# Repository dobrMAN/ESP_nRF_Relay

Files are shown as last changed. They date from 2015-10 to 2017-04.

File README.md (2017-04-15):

# ESP_nRF_Relay



Реле для управления освещением на базе ESP8266 и nRF24L01+

Релейная часть программно аппартного комплекса для управления освещением или другими нагрузками.

Реле реализовано на базе симистора BTA16-600 и управляется WiFi модулем ESP8266 (ESP-03) и подключенным к нему радио модулем nRF24L01+ mini.

**Программная часть:**

Будет дорабатываться в плане настройки готового модуля.

На данный момент программная часть вполне работоспособна и тестируется на макетной плате.

**Аппаратная часть:**

Плата и схема в разработке. Плата не готова к производству, это лишь наброски, который требуется доработать и перепроверить.

**Ссылки на компоненты:**

+ BTA16-600 - http://www.ebay.com/sch/i.html?_from=R40&_trksid=p2050601.m570.l1313.TR0.TRC0.H0.TRS0&_nkw=bta16-600b&_sacat=0

+ MOC3061 - http://www.ebay.com/sch/i.html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

+ ESP-03 - http://www.ebay.com/sch/i.html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

+ nRF24 - http://www.ebay.com/sch/i.html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

+ AC/DC - http://www.ebay.com/sch/i.html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

+ И разная мелочевка.

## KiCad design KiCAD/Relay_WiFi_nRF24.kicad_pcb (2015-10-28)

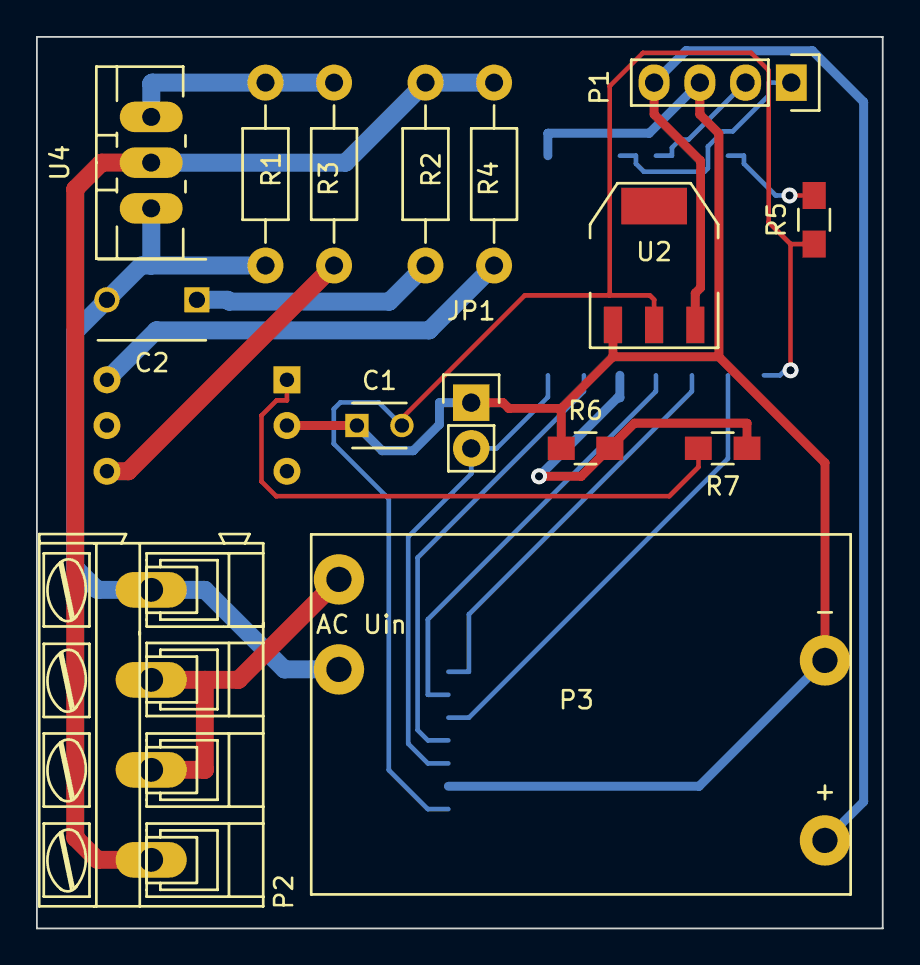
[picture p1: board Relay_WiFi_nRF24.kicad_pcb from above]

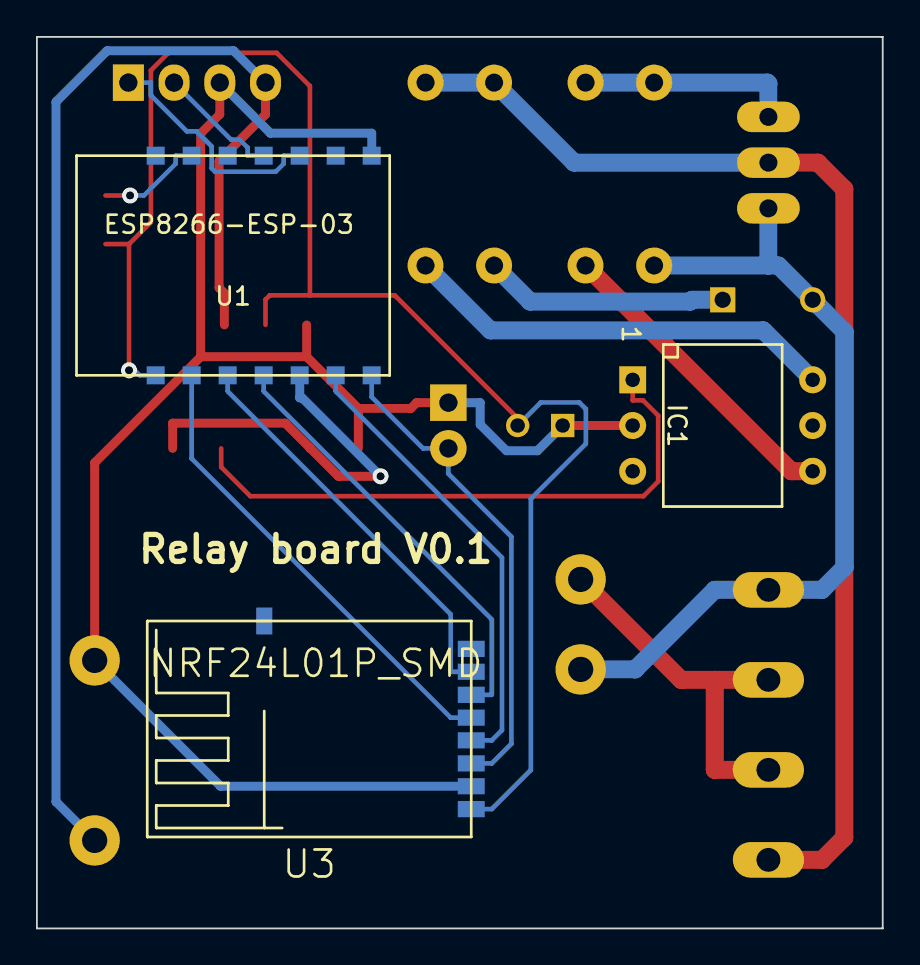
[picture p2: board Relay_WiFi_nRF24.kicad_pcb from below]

Board: 2 copper layers, 47.0 x 49.5 mm, 18 parts (3 on the bottom side), 20 nets.

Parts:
C1: 0.01; C_Disc_D3_P2.5
C2: 10n; C_Disc_D6_P5
IC1: MOC3061M; Optocoupler_6pin_wide_Stile-II
JP1: JUMPER; Pin_Header_Straight_1x02
P1: CONN_4; Pin_Header_Straight_1x04
P2: CONN_4; AK300-4
P3: CONN_01X04; ACDC-FromEbay-5V-700A
R1: 10k; Resistor_Horizontal_RM10mm
R2, R3: 360; Resistor_Horizontal_RM10mm
R4: 39; Resistor_Horizontal_RM10mm
R5, R6: 10k; R_0805_HandSoldering
R7: 220; R_0805_HandSoldering
U1: ESP8266-ESP-03
U2: NCP1117ST33T3G; SOT-223
U3: NRF24L01P_SMD
U4: BTA16; TO-220_Neutral123_Vertical_LargePads

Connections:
GND: C1.1, IC1.2, JP1.1, P1.3, P3.4, R6.1, U1.1, U2.1, U3.2
unnamed: C1.2, R5.1, U1.8, U2.2, U3.1
unnamed: C2.1, R4.2
unnamed: C2.2, P2.4, P3.2, R3.2, U4.1
unnamed: IC1.1, R7.2
unnamed: IC1.4, R1.1
unnamed: IC1.6, R2.1
unnamed: JP1.2, U1.14, U3.3
unnamed: P1.1, U1.3
unnamed: P1.2, U1.4
unnamed: P2.1, R2.2, R4.1, U4.2
unnamed: P2.2, P2.3, P3.1
unnamed: R1.2, R3.1, U4.3
unnamed: R5.2, U1.6
unnamed: R6.2, R7.1, U1.12
unnamed: U1.9, U3.5
unnamed: U1.10, U3.7
unnamed: U1.11, U3.6
unnamed: U1.13, U3.4
VCC: P1.4, P3.3, U2.3

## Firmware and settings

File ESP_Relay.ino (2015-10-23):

#include <ESP8266WiFi.h>
#include <PubSubClient.h>

#include <SPI.h>
#include "nRF24L01.h"
#include "RF24.h"
//#include "printf.h"
#include <Print.h>
const char* ssid = "SSID";
const char* password = "password";
const char* mqtt_server = "x.x.x.x";

const char* topic_info = "/Lights/Room2/Info";
const char* topic_cmd = "/Lights/Room2/Comm";
const char* mqtt_client = "ESP_Room2";

// Set up nRF24L01 radio on SPI bus plus pins 9 & 10 (CE & CS)
RF24 radio(0, 2);
// Single radio pipe address for the 2 nodes to communicate.
const uint64_t pipe = 0xE8E8F0F0E1LL;


int ledPin = 15;
bool ledState = LOW;
uint8_t button_state;

WiFiClient espClient;
PubSubClient client(espClient);
long lastMsg = 0;
char msg[50];
int value = 0;

void setup_wifi() {

  delay(10);

  // We start by connecting to a WiFi network
  //  Serial.println();
  //  Serial.print("Connecting to ");
  //  Serial.println(ssid);

  WiFi.begin(ssid, password);

  while (WiFi.status() != WL_CONNECTED) {
    delay(500);
    //    Serial.print(".");
  }

  //  Serial.println("");
  //  Serial.println("WiFi connected");
  //  Serial.println("IP address: ");
  //  Serial.println(WiFi.localIP());
}

void setup() {
  // set the digital pin as output:
  pinMode(ledPin, OUTPUT);
  Serial.begin(115200);
  //  printf_begin();

  radio.begin();
  radio.openReadingPipe(1, pipe);
  radio.startListening();
  //radio.printDetails();

  setup_wifi();
  client.setServer(mqtt_server, 1883);
  client.setCallback(callback);
  if (!client.connected()) {
    reconnect();
  }

  ledState = HIGH;
  digitalWrite(ledPin, ledState);
  if (ledState) client.publish(topic_cmd, "1"); else client.publish(topic_cmd, "0");
}

void callback(char* topic, byte* payload, unsigned int length) {
  //Serial.print("Message arrived [");
  //Serial.print(topic);
  //Serial.print("] ");
  //for (int i = 0; i < length; i++) {
  //  Serial.print((char)payload[i]);
  //}
  //Serial.println();

  // Switch on the LED if an 1 was received as first character
  if ((char)payload[0] == '0') {
    ledState = LOW;
    digitalWrite(ledPin, ledState);   // Turn the LED on (Note that LOW is the voltage level
    // but actually the LED is on; this is because
    // it is acive low on the ESP-01)
  } else if ((char)payload[0] == '1') {
    ledState = HIGH;
    digitalWrite(ledPin, ledState);  // Turn the LED off by making the voltage HIGH
  } else if ((char)payload[0] == '2') {
    // Switch the LED state
    ledState ^= HIGH;
    digitalWrite(ledPin, ledState);
  } else if ((char)payload[0] == '3') {
    if (ledState) client.publish(topic_cmd, "1"); else client.publish(topic_cmd, "0");
  }
}

void reconnect() {
  // Loop until we're reconnected
  while (!client.connected()) {
    //Serial.print("Attempting MQTT connection...");
    // Attempt to connect
    if (client.connect(mqtt_client)) {
      //Serial.println("connected");
      // Once connected, publish an announcement...
      client.publish(topic_info, "Connected");
      // ... and resubscribe
      client.subscribe(topic_cmd);
    } else {
      //Serial.print("failed, rc=");
      //Serial.print(client.state());
      //Serial.println(" try again in 5 seconds");
      // Wait 5 seconds before retrying
      delay(5000);
    }
  }
}

void loop()
{
  // here is where you'd put code that needs to be running all the time.

  // check to see if it's time to blink the LED; that is, if the
  // difference between the current time and last time you blinked
  // the LED is bigger than the interval at which you want to
  // blink the LED.

  if (!client.connected()) {
    reconnect();
  }

  if ( radio.available() )
  {
    // Dump the payloads until we've gotten everything
    while (radio.available())
    {
      // Fetch the payload, and see if this was the last one.
      radio.read( &button_state, 1 );
      Serial.print("Got buttons ");
      Serial.println(button_state);
      client.publish(topic_info, "Get button " + button_state);
      // For each button, if the button now on, then toggle the LED

      if ( button_state == 2 )
      {
        ledState ^= HIGH;
        digitalWrite(ledPin, ledState);
        if (ledState) client.publish(topic_cmd, "1"); else client.publish(topic_cmd, "0");
      }
    }
  }

  client.loop();

}

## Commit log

2015-10-23 Initial release
    [Relay_WiFi_nRF24.kicad_pcb, Relay_WiFi_nRF24.sch]
2015-10-24 Мелкие изменения
    [Relay_WiFi_nRF24.kicad_pcb]
2015-10-25 Изменение прототипа платы
    Развернул радиомодули, переложил дорожки, увеличил ширину дорожек
    силовой части
    [Relay_WiFi_nRF24.kicad_pcb]
2015-10-25 Update last commit
    [Relay_WiFi_nRF24.kicad_pcb]
2015-10-25 Замена посадочного места блока питания 5V
    Изменил посадочное место блока питания под размеры китайского БП с
    Ebay.com AC/DC-5V-700A
    [Relay_WiFi_nRF24-B.Cu.gbl, Relay_WiFi_nRF24-B.Mask.gbs, Relay_WiFi_nRF24-B.SilkS.gbo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]
2015-10-25 Файлы для производства
    [Relay_WiFi_nRF24-B.Cu.gbl, Relay_WiFi_nRF24-B.Mask.gbs, Relay_WiFi_nRF24-B.SilkS.gbo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]
2015-10-25 Fix изменен путь до библиотект проэкта
2015-10-26 Правка схемы
    Добавлены недостающие подтягивающие резисторы.
    Исправлена библиотека посадочного места коннектора для подключения сети
    и нагрузки.
    Исправлена толщина дорожек.
    Уменьшен размер платы.
    [Relay_WiFi_nRF24-B.Cu.gbl, Relay_WiFi_nRF24-B.Mask.gbs, Relay_WiFi_nRF24-B.SilkS.gbo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]
2015-10-26 Изменения в схеме
    Добавлен токоограничивающий резистр.
    Мелкие правки печатной платы.
    [Relay_WiFi_nRF24-B.Cu.gbl, Relay_WiFi_nRF24-B.Mask.gbs, Relay_WiFi_nRF24-B.SilkS.gbo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]
2015-10-28 [Схема] Надпись на печатной плате
    Просто добавил надпись
    [Relay_WiFi_nRF24-B.Cu.gbl, Relay_WiFi_nRF24-B.Mask.gbs, Relay_WiFi_nRF24-B.SilkS.gbo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]
2015-11-13 Дополнил описание
